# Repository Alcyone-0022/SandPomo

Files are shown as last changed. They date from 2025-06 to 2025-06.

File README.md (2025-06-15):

# SandPomo
University Of Ulsan - 2025-1SEM Open Source Software Term Project

# SandPomo: 모래시계 콘셉트의 뽀모도로 타이머

울산대학교 OSS 텀프로젝트로 개발된 직관적 물리형 뽀모도로 타이머입니다. 숫자 대신 LED와 기울기 등 직관적인 상호작용을 통해 시간의 흐름을 체감할 수 있도록 설계했습니다.

## Project Overview

- **프로젝트명**: SandPomo
- **진행기간**: 2025년 5월 ~ 2025년 6월
- **팀 이름**: 샌드뽀모
- **팀원**: 하승갑 성영준 윤다연 최승우

## Background & Motivation
“시간이란 무엇일까?”라는 질문에서 출발하여, 시간의 흐름을 시각적으로 표현할 수 있는 ‘모래시계’ 콘셉트를 채택하였습니다. 남은 시간을 숫자 대신 LED의 '모래' 양으로 보여줌으로써, 사용자는 숫자에 대한 압박 없이 더 몰입감 있는 시간관리 경험을 할 수 있습니다.

## Adaptiveness with references
- **돌려쓰는 타이머** -> 기울기로 시간 관리 및 조작 기능
<image src="https://github.com/user-attachments/assets/1ab3db29-8078-4ea2-98a9-e818c8478393" width="300"/>

- **모래시계** -> 숫자 없이 시간 흐름 파악
<image src="https://github.com/user-attachments/assets/e6d4aae7-0f3a-43da-9162-da8b4c1f6313" width="300"/>

- **신호등** -> LED를 접목 시켜 시간 흐름을 직관적으로 제공
<image src="https://github.com/user-attachments/assets/ac950b10-1121-4f6d-bb40-97c804a011f8" width="300"/>

## Concept & Main Feature

- **하드웨어 구성**
  - ESP32, ARGB LED 스트립, 자이로 센서
  - 18650 배터리 사용
  - 3D 프린터로 출력한 모래시계 모양 외관
  <image src="https://github.com/user-attachments/assets/07393ead-2a27-4a81-944d-3352364a7195" width="300"/>

- **세션 표시**
  - 집중 시간: 빨간색 LED
  <image src="https://github.com/user-attachments/assets/eef47e84-1c15-4a09-8660-d892abb6a90c" width="300"/>

  - 휴식 시간: 초록색 LED
  <image src="https://github.com/user-attachments/assets/dee28944-4079-4c49-986c-354d38ffd918" width="300"/>

  - 일시정지: 노란색 LED
  <image src="https://github.com/user-attachments/assets/8db5220b-83df-4c03-a20d-a13290a65e1b" width="300"/>
 
  - 세션 표기: 파란색 LED
  <image src="https://github.com/user-attachments/assets/d3e1aa19-b793-49ac-9acb-3205f07439c8" width="300"/>

  - LED가 아래로 내려가는 방식으로 시간 흐름 표현

- **직관적 제어 방식**
  - 기기를 **뒤집으면** 타이머 시작/재시작
  - **눕히면** 일시정지
  - 버튼 없는 물리적 조작

- **소프트웨어 구성**
  - Python과 Tkinter 기반 GUI
  - USB를 통해 타이머 세션 설정 가능
  <image src="https://github.com/user-attachments/assets/855ebb20-bc13-48af-ac07-4f1a52690095" width="300"/>

## Development process

| 단계 | 기간 | 내용 |
|---|---|---|
| 1단계 | ~ 5월 중순 | 주제 선정 및 목표 설정 |
| 2단계 | ~ 5월 하순 | 팀의 강점을 살려 HW 기반 기획 |
| 3단계 | 5~6월 | H/W, S/W, 모델링, 테스트 진행 |
| 4단계 | 6월 이후  | 발표자료 및 시연 영상 제작 |

## Used tools

- **디자인**: Blender, Fusion 360, draw.io
- **프로그래밍**: Python, Tkinter
- **하드웨어**: ESP32, ARGB LED, 3D 프린터 등

## Futeure works

- 키링 크기의 초소형 모델 개발
- 조작의 단순화 및 사용성 개선
- 하드웨어 및 소프트웨어 안정성 강화

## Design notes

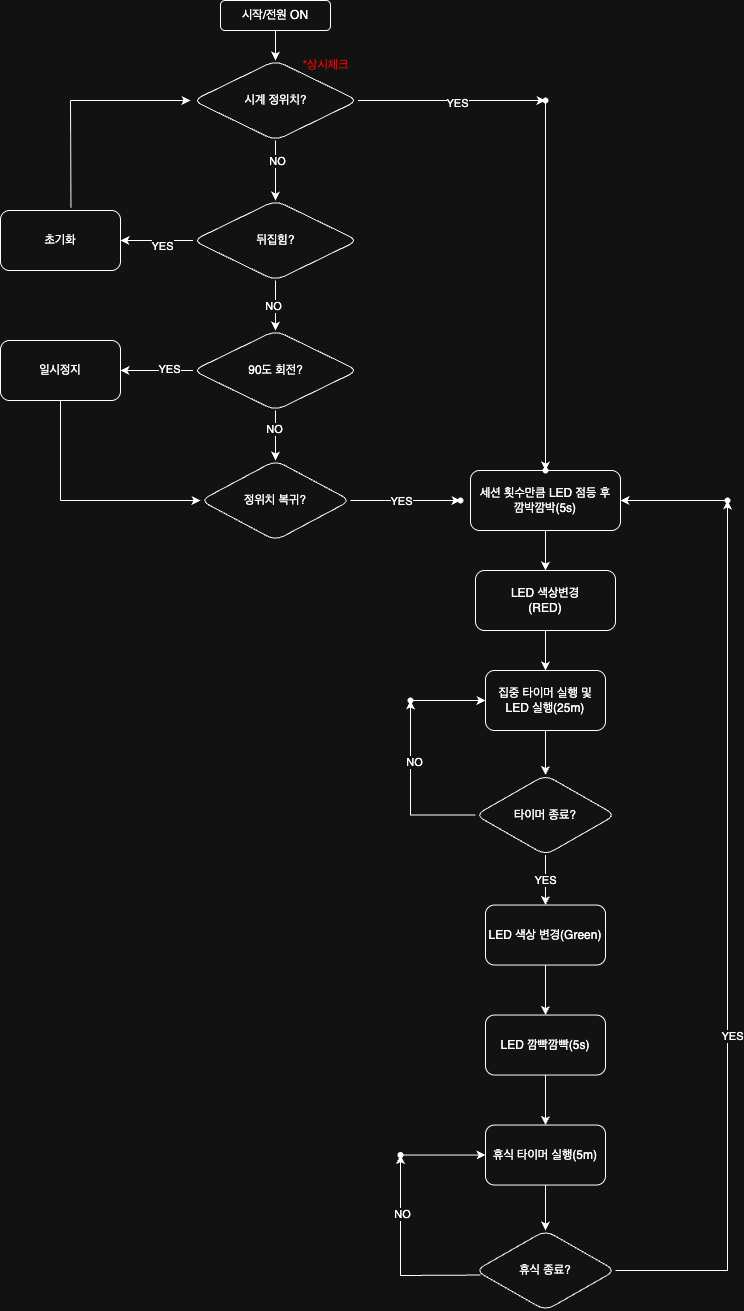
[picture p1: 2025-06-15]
Flow_Chart/2.1_flow_chart.png

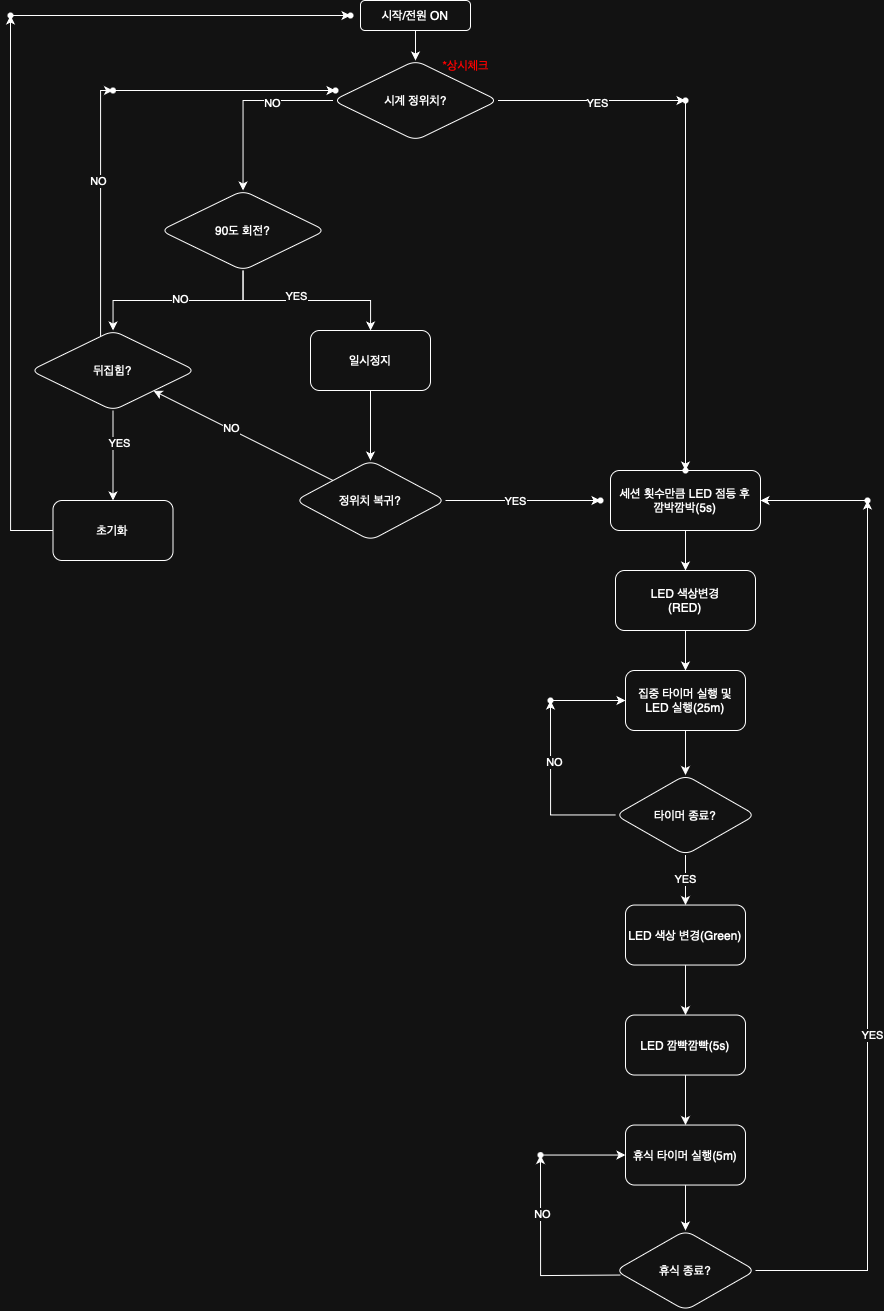
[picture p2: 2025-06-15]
Flow_Chart/2.0_flow_chart.png

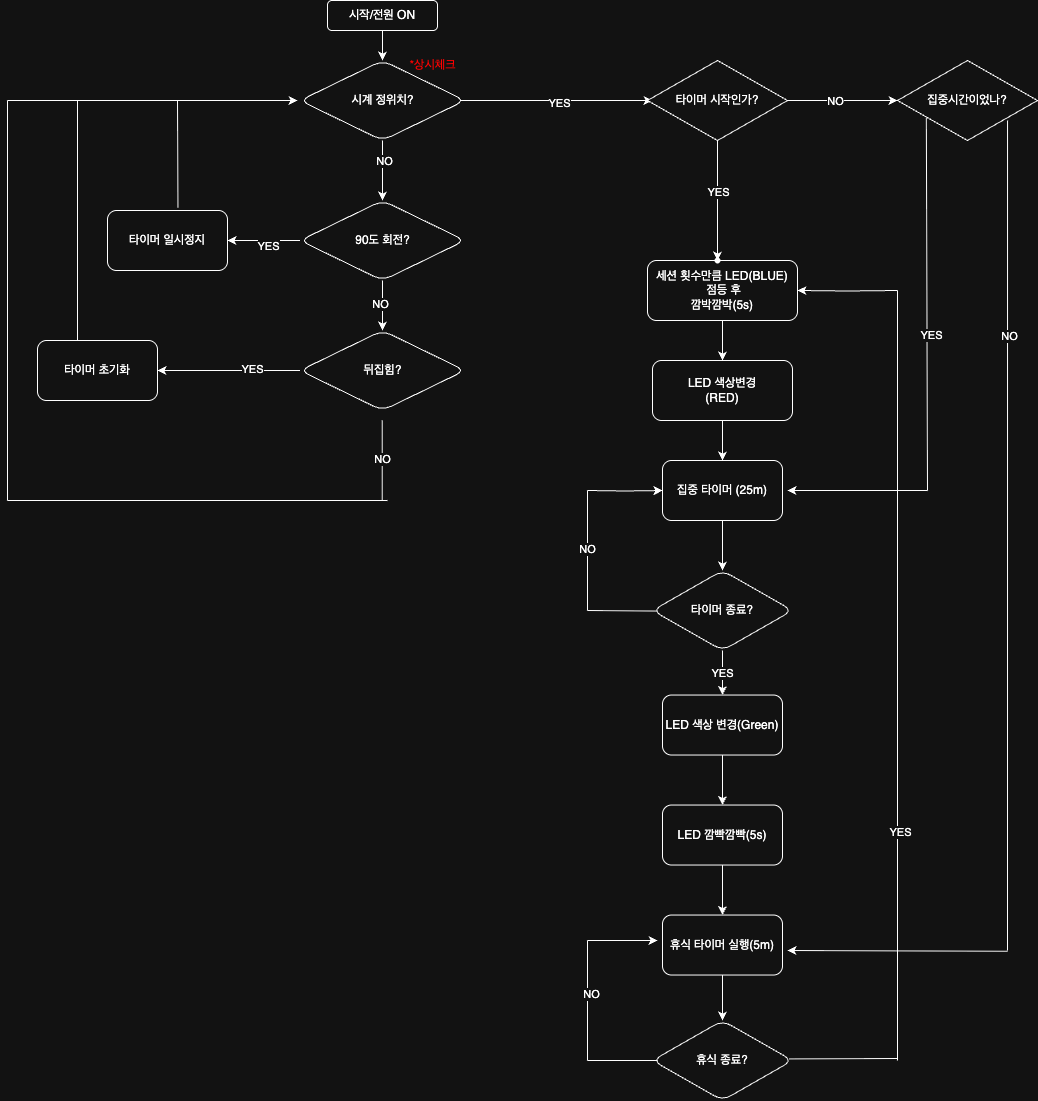
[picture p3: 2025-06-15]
Flow_Chart/2.3_flow_chart.png

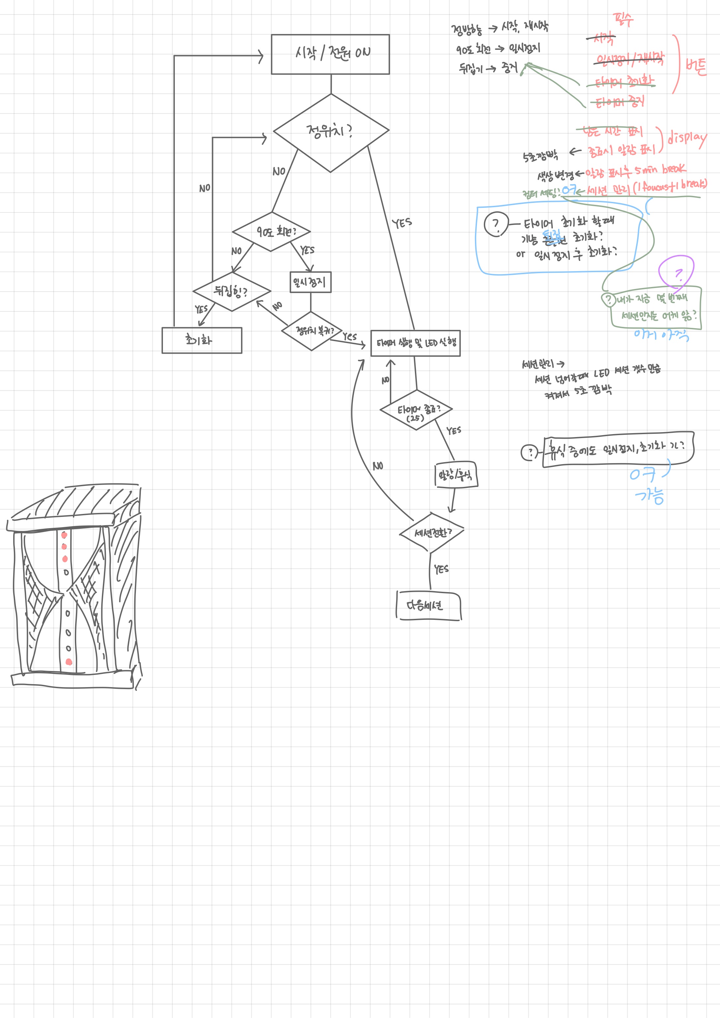
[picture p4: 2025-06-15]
Flow_Chart/1.0_flow_chart.jpg

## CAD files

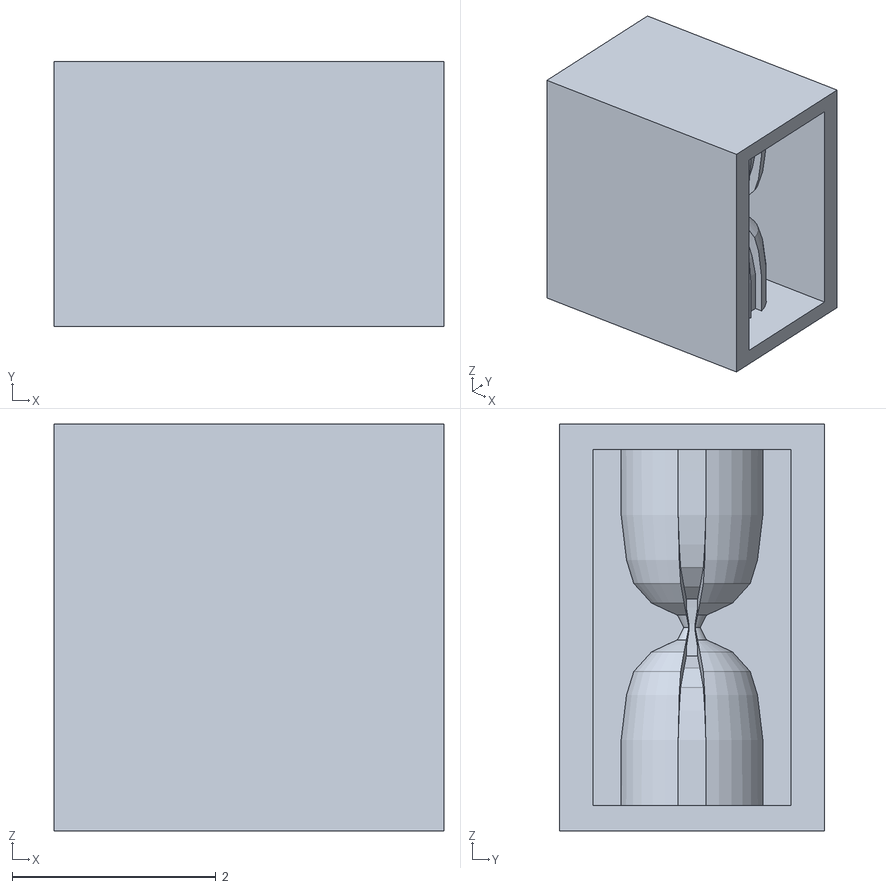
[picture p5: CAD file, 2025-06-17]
modeling/250522 model.stl
3.83 x 2.60 x 4.00

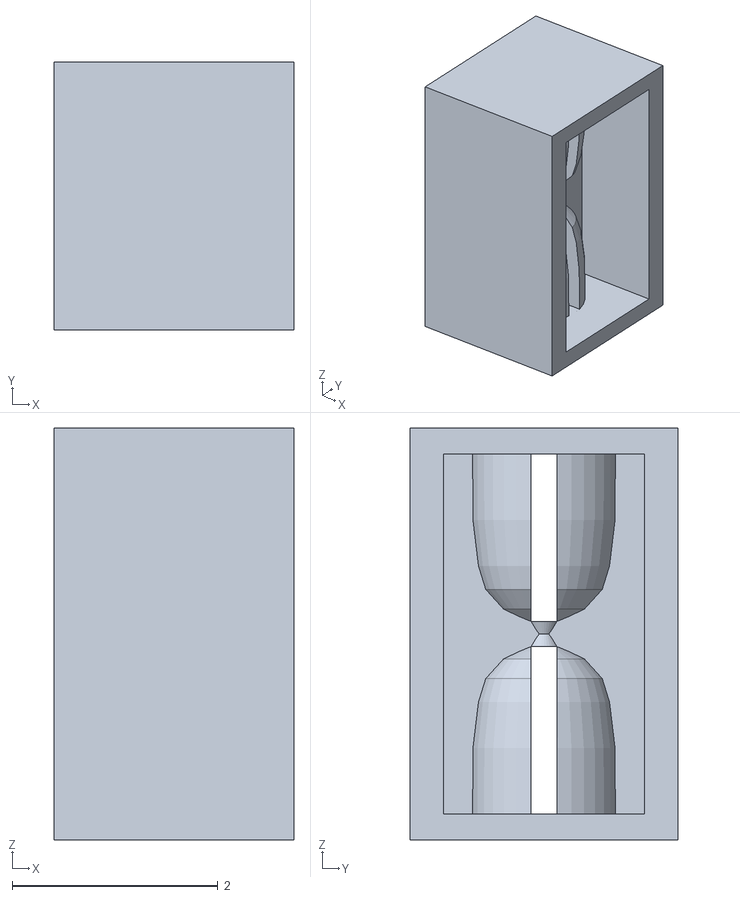
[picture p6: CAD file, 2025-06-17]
modeling/250516 initial modeling v3.obj
2.33 x 2.60 x 4.00

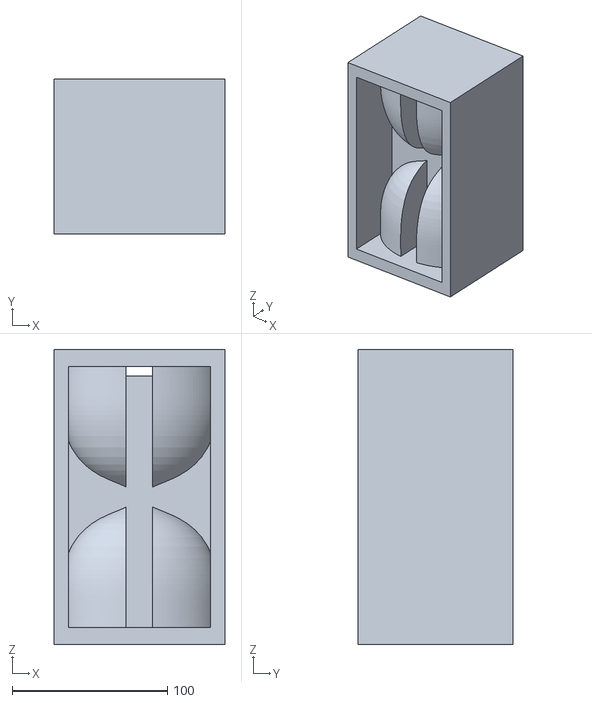
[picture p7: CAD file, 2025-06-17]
modeling/20250529 sandpomo modeling v2.stl
110.0 x 100.0 x 190.0

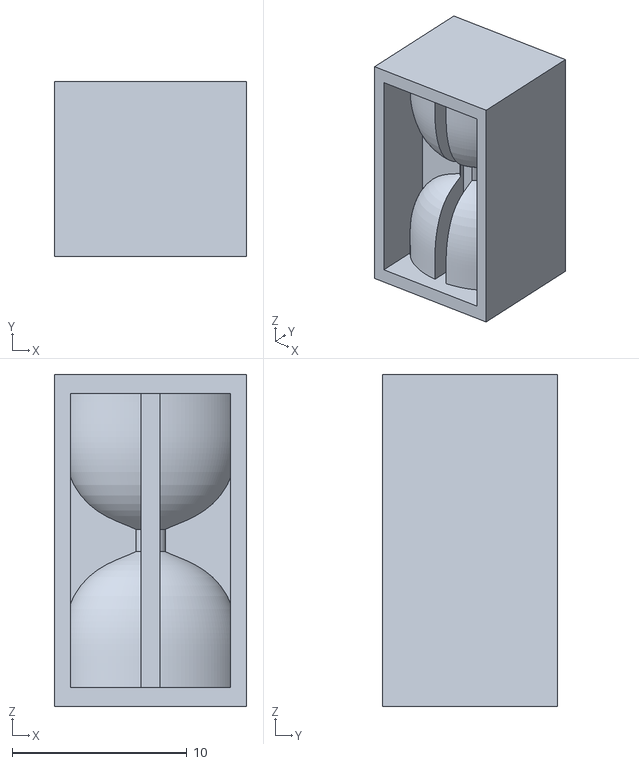
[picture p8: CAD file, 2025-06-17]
modeling/20250529.stl
11.0 x 10.0 x 19.0

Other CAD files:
modeling/250516 initial modeling.stl

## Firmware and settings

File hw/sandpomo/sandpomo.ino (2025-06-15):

#include <Arduino.h>
#include <Adafruit_NeoPixel.h>
#include <Wire.h>
#include <MPU6050_light.h>
#include <EEPROM.h>

#define DEBUG true
#define LED_PIN     8
#define NUM_LEDS    8
#define MAX_BRIGHTNESS 30

Adafruit_NeoPixel strip(NUM_LEDS, LED_PIN, NEO_GRB + NEO_KHZ800);
MPU6050 mpu(Wire);

unsigned long prevMillis = 0;
unsigned long pomodoroTime;
unsigned long restingTime;
unsigned long timeLeft = pomodoroTime;
const uint16_t fadeInterval = 10; // 밝기 갱신 주기(ms)

// for serial input
int num1 = 0;
int num2 = 0;
String inputString = "";

bool isTimeUp = false;

byte upperLedVal = MAX_BRIGHTNESS;
byte middle2LedVal = MAX_BRIGHTNESS;
byte middle1LedVal = MAX_BRIGHTNESS;
byte lowerLedVal = MAX_BRIGHTNESS;

// 색상 모드 열거형
enum ColorMode { RED, GREEN };
ColorMode modeNow = RED;

enum upDownState { UP, DOWN };
upDownState posNow;
upDownState posPrev;

enum angleState { VERTICAL, HORIZONTAL };
angleState angleNow = VERTICAL;

bool upsideDown = false;
bool tick = false; // for blinking led when usb connected

byte sessionCnt = 0;

//**** Forwards ****
void setLED(byte upper, byte mid2, byte mid1, byte lower, bool reverse, ColorMode colorMode);
void setLEDYellow();
void setLEDRed();
void setLEDVal(unsigned long timerNow, unsigned long timeLeft);
void listenToSerial();
void showSessionCnt();
upDownState getPosNow();
angleState getAngleNow();
bool isUpsideDown();

void setup() {
  Serial.begin(115200);
  EEPROM.begin(8);
  Wire.setPins(3, 4);
  Wire.begin();

  byte status = mpu.begin();
  while(status != 0){ 
    status = mpu.begin();
    Serial.println("NO MPU FOUND!");
    delay(100);
  } // 센서 연결 확인
  // mpu.calcOffsets();  // 자이로/가속도계 오프셋 계산

  setLEDYellow();

  // for initial calibration of MPU
  prevMillis = millis();
  while (millis() - prevMillis <= 1000) {
    mpu.update();
  }

  // set time values from EEPROM
  setTimeVal();

  posNow = getPosNow();
  posPrev = getPosNow();
  
  // stop time till fliped when initialized
  while (posPrev == posNow) {
    posNow = getPosNow();
    Serial.println((posNow == UP) ? "UP" : "DOWN");
    // blocking function. listen to serial to get config values
    listenToSerial();
    setLED(upperLedVal, middle2LedVal, middle1LedVal, lowerLedVal, (posNow == UP) ? true : false, modeNow);
    delay(100);
  }
  
}

void loop() {

  // blocking function. listen to serial to get config values
  if (!DEBUG) { listenToSerial(); }

  if (millis() - prevMillis >= fadeInterval) {
    prevMillis = millis();
  
    unsigned long timerNow = (modeNow == RED) ? pomodoroTime : restingTime;

    if (DEBUG) {
      Serial.print(upperLedVal); Serial.print(" "); Serial.print(middle2LedVal); Serial.print(" "); Serial.print(middle1LedVal); Serial.print(" "); Serial.println(lowerLedVal);
      // Serial.print(pomodoroTime); Serial.print(" "); Serial.println(restingTime);
      Serial.print(timerNow); Serial.print(" "); Serial.println(timeLeft);

      mpu.update();
      float pitch = mpu.getAngleY(); // 보정된 Pitch
      float roll = mpu.getAngleX();  // 보정된 Roll
      Serial.print("Roll: ");
      Serial.print(roll);
      Serial.print("°\tPitch: ");
      Serial.print(pitch);
      Serial.println("°");
  
      // 자세 판별
      if(getAngleNow() == VERTICAL) {
        Serial.println("Upright position");
      } else {
        Serial.println("Lying down (side) position");
      }
  
      // uplight 방향 판별
      if (getPosNow() == UP) {
        Serial.println("UP STATE");
      } else if (getPosNow() == DOWN) {
        Serial.println("DOWN STATE");
      }

      if (isUpsideDown()) {
        Serial.println("UPSIDE DOWN STATE");
      }
    }
  
    // Control timer and current mode at this section
    if (timeLeft - fadeInterval >= fadeInterval && !isTimeUp) {
      isTimeUp = false;

      setLEDVal(timerNow, timeLeft);
      posNow = getPosNow();
      setLED(upperLedVal, middle2LedVal, middle1LedVal, lowerLedVal, (posNow == UP) ? false : true, modeNow);

      // if lying down side, stop timer
      if (getAngleNow() == HORIZONTAL) {
        setLEDYellow();
        Serial.println("TIME STOPPED");
      } else if (isUpsideDown()){
        // if upside down, initialize timer
        timerNow = pomodoroTime;
        timeLeft = timerNow;
        modeNow = RED;
        setLEDRed();
        Serial.println("TIME INITIALIZED");
      } else {
        // elapse current timer
        timeLeft = timeLeft - fadeInterval;
      }
    } else {
      // TIME IS UP!

      // initialize timer once!
      if (!isTimeUp) {
        // initialize timer
        if ( modeNow == RED) {
          // colormod now is pomodoro
          // change to resting
          timeLeft = restingTime;
        } else {
          // colormod now is resting
          // change to pomodoro
          timeLeft = pomodoroTime;

          // increase session count
          sessionCnt++;
        }
        
        showSessionCnt();

        // change colormod
        modeNow = (modeNow == RED) ? GREEN : RED;

        // initialize led brightness val
        upperLedVal = MAX_BRIGHTNESS;
        middle2LedVal = MAX_BRIGHTNESS;
        middle1LedVal = MAX_BRIGHTNESS;
        lowerLedVal = MAX_BRIGHTNESS;

        // change led color to opposite
        setLED(upperLedVal, middle2LedVal, middle1LedVal, lowerLedVal, (posNow == UP) ? true : false, modeNow);

        posPrev = getPosNow();
        isTimeUp = true;
      }
      
      // stop time till fliped
      if (posPrev == posNow) {
        posNow = getPosNow();
        // well... actually this delay will not block main loop.
        delay(100);
      }

      // exit timeup state (end waiting flip)
      if (posPrev != posNow) {
        isTimeUp = false;
      }
    
    }
  }
}

void setLED(byte upper, byte mid2, byte mid1, byte lower, bool reverse, ColorMode colorMode) {
  strip.clear();
  
  uint8_t r = (colorMode == RED) ? upper : 0;
  uint8_t g = (colorMode == GREEN) ? upper : 0;
  uint8_t r_mid2 = (colorMode == RED) ? mid2 : 0;
  uint8_t g_mid2 = (colorMode == GREEN) ? mid2 : 0;
  uint8_t r_mid1 = (colorMode == RED) ? mid1 : 0;
  uint8_t g_mid1 = (colorMode == GREEN) ? mid1 : 0;
  uint8_t r_lower = (colorMode == RED) ? lower : 0;
  uint8_t g_lower = (colorMode == GREEN) ? lower : 0;

  if (!reverse) {
    strip.setPixelColor(0, r, g, 0, 0);
    strip.setPixelColor(1, r_mid2, g_mid2, 0, 0);
    strip.setPixelColor(2, r_mid1, g_mid1, 0, 0);
    strip.setPixelColor(3, r_lower, g_lower, 0, 0);
    strip.setPixelColor(4, 
      (colorMode == RED) ? (MAX_BRIGHTNESS - lower) : 0,
      (colorMode == GREEN) ? (MAX_BRIGHTNESS - lower) : 0, 
      0, 0);
    strip.setPixelColor(5, 
      (colorMode == RED) ? (MAX_BRIGHTNESS - mid1) : 0,
      (colorMode == GREEN) ? (MAX_BRIGHTNESS - mid1) : 0, 
      0, 0);
    strip.setPixelColor(6, 
      (colorMode == RED) ? (MAX_BRIGHTNESS - mid2) : 0,
      (colorMode == GREEN) ? (MAX_BRIGHTNESS - mid2) : 0, 
      0, 0);
    strip.setPixelColor(7, 
      (colorMode == RED) ? (MAX_BRIGHTNESS - upper) : 0,
      (colorMode == GREEN) ? (MAX_BRIGHTNESS - upper) : 0, 
      0, 0);
  } else {
    strip.setPixelColor(7, r, g, 0, 0);
    strip.setPixelColor(6, r_mid2, g_mid2, 0, 0);
    strip.setPixelColor(5, r_mid1, g_mid1, 0, 0);
    strip.setPixelColor(4, r_lower, g_lower, 0, 0);
    strip.setPixelColor(3, 
      (colorMode == RED) ? (MAX_BRIGHTNESS - lower) : 0,
      (colorMode == GREEN) ? (MAX_BRIGHTNESS - lower) : 0, 
      0, 0);
    strip.setPixelColor(2, 
      (colorMode == RED) ? (MAX_BRIGHTNESS - mid1) : 0,
      (colorMode == GREEN) ? (MAX_BRIGHTNESS - mid1) : 0, 
      0, 0);
    strip.setPixelColor(1, 
      (colorMode == RED) ? (MAX_BRIGHTNESS - mid2) : 0,
      (colorMode == GREEN) ? (MAX_BRIGHTNESS - mid2) : 0, 
      0, 0);
    strip.setPixelColor(0, 
      (colorMode == RED) ? (MAX_BRIGHTNESS - upper) : 0,
      (colorMode == GREEN) ? (MAX_BRIGHTNESS - upper) : 0, 
      0, 0);
  }
  strip.show();
}

void setLEDYellow() {
  for (byte i = 0; i < NUM_LEDS; i++) {
    strip.setPixelColor(i, 20, 20, 0, 0);
  }
  strip.show();
}

void setLEDRed() {
  for (byte i = 0; i < NUM_LEDS; i++) {
    strip.setPixelColor(i, 20, 0, 0, 0);
  }
  strip.show();
}

void setLEDVal(unsigned long timerNow, unsigned long timeLeft) {
  // calculate and set led values
  if (timeLeft > timerNow * 3 / 4) {
    // upper LED: 255 → 0
    upperLedVal = map(timeLeft, timerNow, timerNow * 3 / 4, MAX_BRIGHTNESS, -1);
  } else if (timeLeft > timerNow * 2 / 4) {
    // middle2 LED: 255 → 0
    middle2LedVal = map(timeLeft, timerNow * 3 / 4, timerNow * 2 / 4, MAX_BRIGHTNESS, -1);
  } else if (timeLeft > timerNow * 1 / 4) {
    // middle1 LED: 255 → 0
    middle1LedVal = map(timeLeft, timerNow * 2 / 4, timerNow * 1 / 4, MAX_BRIGHTNESS, -1);
  } else {
    // lower LED: 255 → 0
    lowerLedVal = map(timeLeft, timerNow * 1 / 4, 0, MAX_BRIGHTNESS, -1);
  }
}

void setTimeVal(){
  int read1;
  int read2;

  EEPROM.get(0, read1);
  EEPROM.get(4, read2);

  pomodoroTime = read1 * 60 * 1000;
  restingTime = read2 * 60 * 1000;
  timeLeft = pomodoroTime;
}

void listenToSerial() {
  while (Serial) {
    if (millis() - prevMillis >= 2000) {
      prevMillis = millis();
      tick = !tick;
    }

    if (tick) {
        setLEDYellow();
      } else {
        strip.clear();
        strip.show();
    }

    if (Serial.available()) {
      char inChar = (char)Serial.read();
      if (inChar == '\n' || inChar == '\r') { // 엔터(줄바꿈) 입력 시 처리
        inputString.trim(); // 앞뒤 공백 제거
        int spaceIndex = inputString.indexOf(' ');
        if (spaceIndex > 0) {
          String firstNum = inputString.substring(0, spaceIndex);
          String secondNum = inputString.substring(spaceIndex + 1);
          num1 = firstNum.toInt();
          num2 = secondNum.toInt();
          Serial.print("첫 번째 숫자: ");
          Serial.println(num1);
          Serial.print("두 번째 숫자: ");
          Serial.println(num2);

          EEPROM.put(0, num1);
          EEPROM.put(4, num2);
          EEPROM.commit();
          setTimeVal();
        } else {
          Serial.println("입력 형식이 올바르지 않습니다!");
        }
        inputString = ""; // 입력 문자열 초기화
      } else {
        inputString += inChar;
      }
    }
  }
}

upDownState getPosNow() {
  mpu.update();
  // uplight 방향 판별
  if (mpu.getAngleX() < -80 && abs(mpu.getAngleY()) < 10) {
    return UP;
  } else if (mpu.getAngleX() > 80 && abs(mpu.getAngleY()) < 10) {
    return DOWN;
  }
}

angleState getAngleNow() {
  mpu.update();
  if (abs(mpu.getAngleY()) > 80) {
    return HORIZONTAL;
  } else {
    return VERTICAL;
  }
}

bool isUpsideDown() {
  mpu.update();
  if (abs(mpu.getAngleX()) > 170) {
    return true;
  } else {
    return false;
  }
}

void showSessionCnt() {
  if (sessionCnt == 0) return;

  strip.clear();
  strip.show();

  // 3번 깜빡임
  for (byte i = 0; i < 3; i++) {
    if (posNow == DOWN) {
      for (byte ii = 0; ii < sessionCnt % 8; ii++){
        strip.setPixelColor(ii, 20, 20, 20, 0);
      }
    } else {
      for (byte ii = 7; ii > 7 - (sessionCnt % 8); ii--){
        strip.setPixelColor(ii, 20, 20, 20, 0);
      }
    }
    strip.show();
    delay(500);
    strip.clear();
    strip.show();
    delay(500);
  }

}

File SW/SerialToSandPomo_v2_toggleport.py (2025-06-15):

import tkinter as tk
from tkinter import ttk
import serial
import serial.tools.list_ports
import time

BAUD_RATE = 115200 

def list_serial_ports():
    ports = serial.tools.list_ports.comports()
    port_list = []
    for port in ports:
        label = f"{port.device} ({port.description})"
        port_list.append(label)
    return port_list

def get_device_from_label(label):
    return label.split(' ')[0]

def connect_serial():
    global ser
    selected_label = port_combo.get()
    if not selected_label:
        status_label.config(text="포트를 선택하세요.", fg="red")
        return
    port = get_device_from_label(selected_label)
    try:
        ser = serial.Serial(port, BAUD_RATE, timeout=1)
        time.sleep(2)
        status_label.config(text=f"{port} 연결 성공", fg="green")
    except Exception as e:
        ser = None
        status_label.config(text=f"연결 실패: {e}", fg="red")

def send_time():
    if ser is None or not ser.is_open:
        status_label.config(text="시리얼 연결 안 됨", fg="red")
        return
    session = session_entry.get()
    brk = break_entry.get()
    if not (session.isdigit() and brk.isdigit()):
        status_label.config(text="숫자를 입력하세요.", fg="red")
        return
    try:
        # "Session,Break\n" 형식으로 전송
        ser.write(f"{session} {brk}\n".encode())
        status_label.config(text=f"Session: {session}분, Break: {brk}분 전송 완료", fg="yellow")
    except Exception as e:
        status_label.config(text=f"전송 실패: {e}", fg="red")

def refresh_ports():
    port_combo['values'] = list_serial_ports()
    status_label.config(text="포트 목록 갱신", fg="black")

def validate_entries(*args):
    session = session_var.get()
    brk = break_var.get()
    if session.isdigit() and brk.isdigit() and int(session) > 0 and int(brk) > 0:
        send_button.config(state="normal")
    else:
        send_button.config(state="disabled")

root = tk.Tk()
root.title("SandPomo")

title_label = tk.Label(root, text="SandPomo", font=("Arial", 18, "bold"))
title_label.grid(row=0, column=0, columnspan=4, pady=10)

tk.Label(root, text="포트 선택").grid(row=1, column=0, padx=5, pady=5)
port_combo = ttk.Combobox(root, width=35, state="readonly")
port_combo['values'] = list_serial_ports()
port_combo.grid(row=1, column=1, padx=5, pady=5, columnspan=2)
refresh_button = tk.Button(root, text="새로고침", command=refresh_ports)
refresh_button.grid(row=1, column=3, padx=5, pady=5)

connect_button = tk.Button(root, text="연결", command=connect_serial)
connect_button.grid(row=2, column=1, padx=5, pady=5, sticky="ew", columnspan=2)

# Session과 Break 입력을 위한 중앙 Frame 생성
input_frame = tk.Frame(root)
input_frame.grid(row=3, column=0, columnspan=4, pady=20)

# Session 입력 (라벨과 Entry를 나란히 배치)
session_label = tk.Label(input_frame, text="Session 시간 입력:")
session_label.grid(row=0, column=0, padx=5, pady=5)
session_var = tk.StringVar()
session_var.trace_add('write', validate_entries)
session_entry = tk.Entry(input_frame, width=10, textvariable=session_var, justify="center")
session_entry.grid(row=0, column=1, padx=5, pady=5)

# Break 입력 (라벨과 Entry를 나란히 배치)
break_label = tk.Label(input_frame, text="Break 시간 입력:")
break_label.grid(row=1, column=0, padx=5, pady=5)
break_var = tk.StringVar()
break_var.trace_add('write', validate_entries)
break_entry = tk.Entry(input_frame, width=10, textvariable=break_var, justify="center")
break_entry.grid(row=1, column=1, padx=5, pady=5)

# 전송 버튼도 Frame 안에 중앙 배치
send_button = tk.Button(input_frame, text="전송", command=send_time, state="disabled")
send_button.grid(row=2, column=0, columnspan=2, padx=5, pady=10)

# 상태 라벨
status_label = tk.Label(root, text="", fg="blue")
status_label.grid(row=4, column=0, columnspan=4, pady=10)

ser = None

root.mainloop()

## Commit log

2025-06-14 기본 뼈대 잡아놓기
2025-06-15 merge Develop/HW PoC to main (#2)
    * initialize platformio
    * implement led fade & direction
    * add forward to solve compilation error
    * fix gradation to easy-detectable brightness
    * change platform
    * change platform
    * change platform (finally working)
    * implement basic dim
    * add colormod
    * update gitignore
    * now timer varies with modeNow
    * upright/lying down position
    * implement up/down state | LED direction
    * remove unnecessary files
    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
    [sandpomo.ino]
2025-06-15 Develop/flow chart (#4)
    * initial flowchart
    * second commit
    * third commit
    * 4th commit
    * 5th commit
    ---------
2025-06-15 Serial Communication Developed (#3)
    * Create SerialToSandPomo_v1_autodetect.py
    자동으로 포트를 잡고 시리얼 통신이 가능한 데모 버전입니다. 현재는 세션만 보낼 수 있고, 자동 포트가 감지 가능한 MCU는 ESP류입니다.
    * Create SerialToSandPomo_v2_toggleport.py
    토글 리스트로 포트를 보여주고, 포트를 선택할 수 있습니다.
    포트 선택 후 해당 포트로 시리얼 통신이 가능한 데모 버전입니다. 현재는 세션만 보낼 수 있습니다.
    * Update SerialToSandPomo_v1_autodetect.py
    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
2025-06-15 이미지 추가
2025-06-17 merge modeling branch (#5)
    * 0516 initial modeling
    * modeling feedback commit
    * 시계에 홈이 파인 모델링
    * WS2812B Strip 4ea modeling
    * 250525 feedback modeling
    * Add files via upload
    수정된 모델링입니다.
    * 20250529 modeling fix
    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
    [20250529 sandpomo modeling v2.stl, 20250529.stl, 250516 initial modeling v3.obj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]
